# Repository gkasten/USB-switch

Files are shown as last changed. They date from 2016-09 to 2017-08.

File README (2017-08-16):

These scripts work with a USB switcher board to enable automated testing of an
Android device in host mode. They were written as part of Benjamin Fair's
(benjaminfair@) internship during summer 2016. For more information contact his
host Glenn Kasten (gkasten@).

In order to use the scripts in this directory, you must install some
dependencies. These dependencies vary based on which version of the board you
wish to use. See below for more information.

The scripts require a udev rules file to be installed which is included as
"49-ftdi.rules". Install it to "/etc/udev/rules.d/49-ftdi.rules" then run
"udevadm trigger" as root or reboot. The scripts can also be run as root instead
of installing the rules file.

The following kernel drivers/modules may interfere with access to the ftdi
chip on the board and so may have to be unloaded/blacklisted:
        ftdi_sio
        usbserial

usbswitch.py    Supports initial USB switch prototype with an Adafruit FT232H
                GPIO chip. Requires Adafruit_GPIO library from
                https://github.com/adafruit/Adafruit_Python_GPIO

usbswitch2.py   Supports new single-board switch (red PCB). Only requires
                libftdi1-dev which is in most distributions' repos. Could easily
                be ported to C and statically compiled to eliminate all
                dependencies.

adb.sh          Simple wrapper for adb that handles switching to debug mode and
                back to run mode after executing a command.

full.sh         Example script that shows how to use the switch to run tests
                using the WALT device and app in a fully automated way.

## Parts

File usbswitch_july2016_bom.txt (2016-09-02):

Partlist exported from /usr/local/google/home/benjaminfair/eagle/usbswitch2/usbswitch_july2016.sch at 8/1/16 6:14 PM

Part Value            Device           Package          Description                       MF MPN OC_FARNELL OC_NEWARK
C1   4.7uF            C-USC1210K       C1210K           CAPACITOR, American symbol                                   
C2   0.1uF            C-USC0805K       C0805K           CAPACITOR, American symbol                                   
C3   0.1uF            C-USC0805K       C0805K           CAPACITOR, American symbol                                   
C4   0.1uF            C-USC0805K       C0805K           CAPACITOR, American symbol                                   
C5   0.1uF            C-USC0805K       C0805K           CAPACITOR, American symbol                                   
IC1  MAX4906ELA       MAX4906ELA       UDFN10           High-/Full-Speed USB 2.0 Switches        unknown    unknown  
JP1  MOLEX-47346-0001 MOLEX-47346-0001 MOLEX-47364-0001 MICRO USB B, BOTTOM MOUNT                                    
JP2                   PN87520          PN87520          BERG USB connector                       unknown    unknown  
JP3  MOLEX-47346-0001 MOLEX-47346-0001 MOLEX-47364-0001 MICRO USB B, BOTTOM MOUNT                                    
JP4                   PINHD-1X5        1X05             PIN HEADER                                                   
Q1   FDN336P          PMOSSOT23        SOT-23           MOS FET                                  unknown    unknown  
Q2   FDN336P          PMOSSOT23        SOT-23           MOS FET                                  unknown    unknown  
Q3   FDN335N          NMOSSTO23        SOT-23           MOS FET                                                      
Q4   FDN335N          NMOSSTO23        SOT-23           MOS FET                                                      
R1   10K              R-US_R0805W      R0805W           RESISTOR, American symbol                                    
R2   10K              R-US_R0805W      R0805W           RESISTOR, American symbol                                    
R3   10K              R-US_R0805W      R0805W           RESISTOR, American symbol                                    
R4   10K              R-US_R0805W      R0805W           RESISTOR, American symbol                                    
R6   10K              R-US_R0805W      R0805W           RESISTOR, American symbol                                    
R7   10K              R-US_R0805W      R0805W           RESISTOR, American symbol                                    
R8   10K              R-US_R0805W      R0805W           RESISTOR, American symbol                                    
R_ID 124K             R-US_R0805W      R0805W           RESISTOR, American symbol                                    
U1   FT245RL          FT245RL          SSOP28DB         USB FIFO Controller

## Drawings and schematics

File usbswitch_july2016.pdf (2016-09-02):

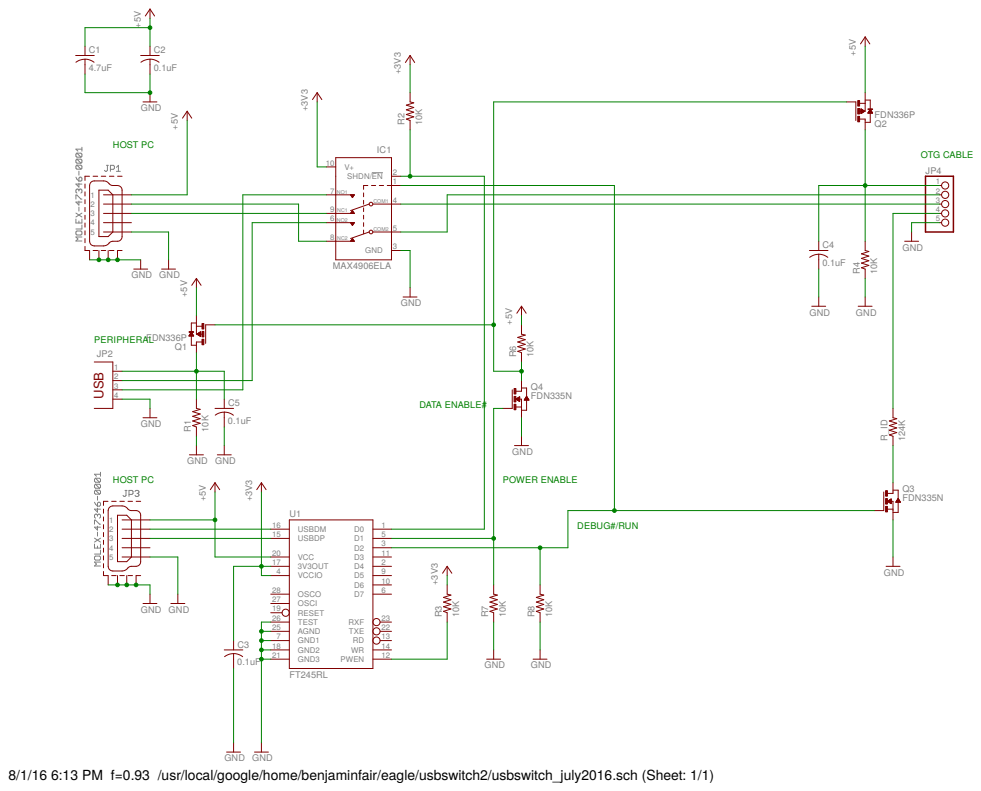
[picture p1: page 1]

4 | C5

8/1/16 6:13 PM f=0.93 /usr/local/google/home/benjaminfair/eagle/usbswitch2/usbswitch_july2016.sch (Sheet: 1/1)

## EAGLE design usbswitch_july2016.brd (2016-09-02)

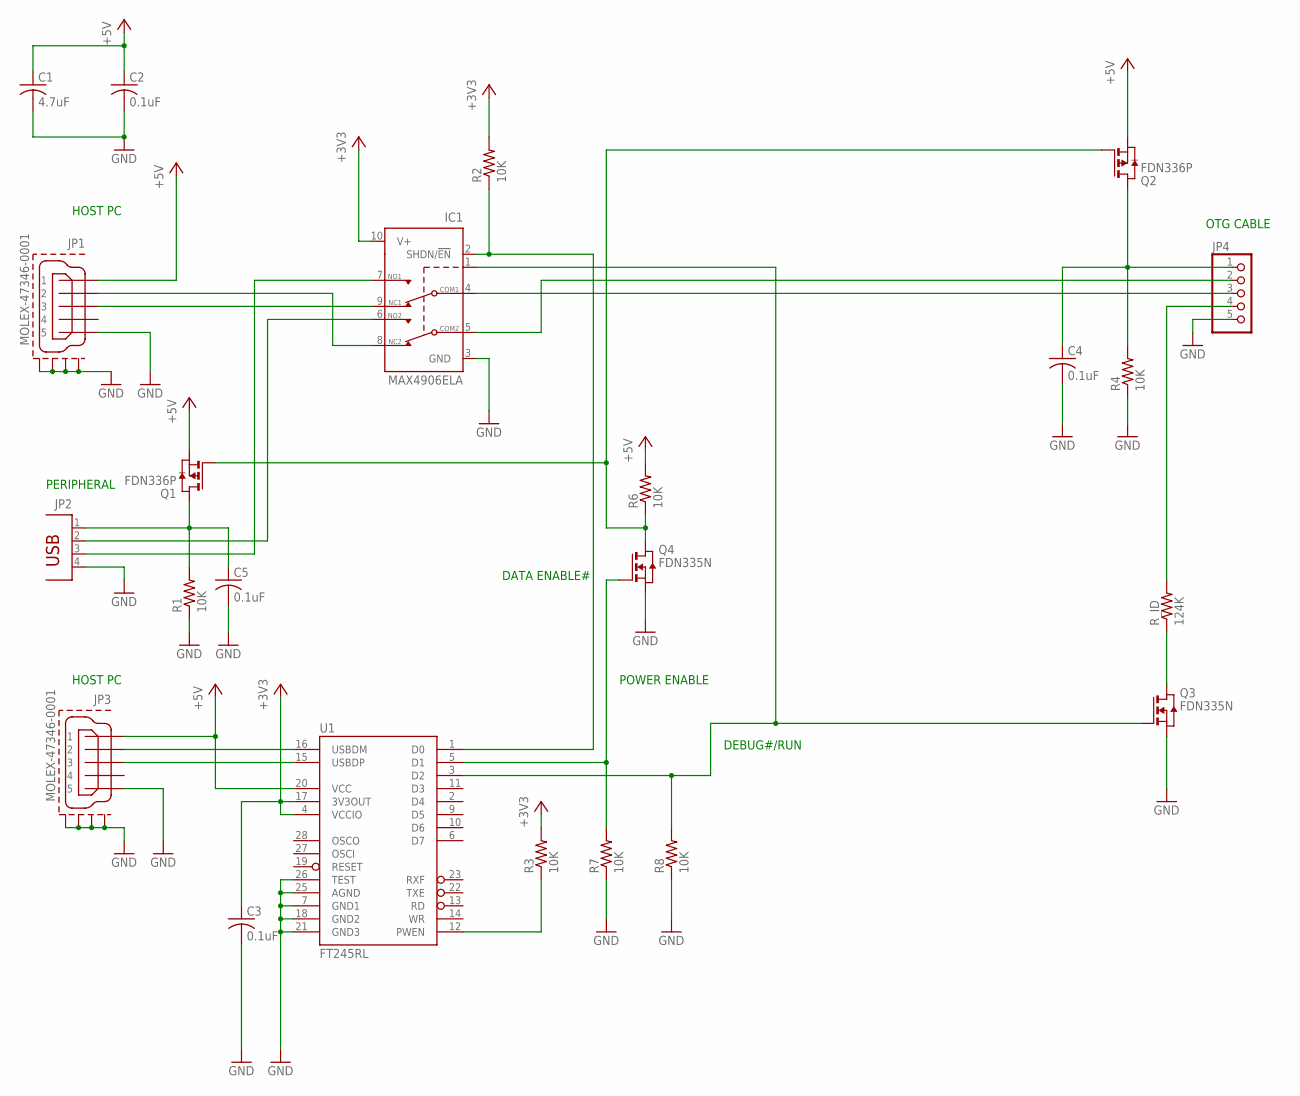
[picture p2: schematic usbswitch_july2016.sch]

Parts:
C1: 4.7uF; C1210K
C2, C3, C4, C5: 0.1uF; C0805K
IC1: MAX4906ELA; UDFN10
JP1, JP3: MOLEX-47346-0001; MOLEX-47364-0001
JP2: PN87520
JP4: PINHD-1X5; 1X05
Q1, Q2: FDN336P; SOT-23
Q3, Q4: FDN335N; SOT-23
R1, R2, R3, R4, R6, R7, R8: 10K; R0805W
R_ID: 124K; R0805W
U1: FT245RL; SSOP28DB

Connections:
+3V3: C3.1, IC1.10 (V+), R2.2, R3.2, U1.4 (VCCIO), U1.17 (3V3OUT)
+5V: C1.1, C2.1, JP1.1, JP3.1, Q1.2 (S), Q2.2 (S), R6.2, U1.20 (VCC)
GND: C1.2, C2.2, C3.2, C4.2, C5.2, IC1.3 (GND), JP1.5, JP1.GND1, JP1.GND2, JP1.GND3, JP1.GND4, JP2.4, JP3.5, JP3.GND1, JP3.GND2, JP3.GND3, JP3.GND4, JP4.5, Q3.2 (S), Q4.2 (S), R1.1, R4.1, R7.1, R8.1, U1.7 (GND1), U1.18 (GND2), U1.21 (GND3), U1.25 (AGND), U1.26 (TEST)
unnamed: IC1.4 (COM1), JP4.3
unnamed: IC1.2 (SHDN/!EN), R2.1, U1.1 (D0)
unnamed: C5.1, JP2.1, Q1.1 (D), R1.2
unnamed: C4.1, JP4.1, Q2.1 (D), R4.2
unnamed: IC1.9 (NC1), JP1.3
unnamed: IC1.8 (NC2), JP1.2
unnamed: Q3.1 (D), R_ID.1
unnamed: Q4.3 (G), R7.2, U1.5 (D1)
unnamed: IC1.6 (NO2), JP2.2
unnamed: IC1.7 (NO1), JP2.3
unnamed: JP3.2, U1.16 (USBDM)
unnamed: IC1.1 (IN), Q3.3 (G), R8.2, U1.3 (D2)
unnamed: Q1.3 (G), Q2.3 (G), Q4.1 (D), R6.1
unnamed: R3.1, U1.12 (PWEN)
unnamed: JP4.4, R_ID.2
unnamed: IC1.5 (COM2), JP4.2
unnamed: JP3.3, U1.15 (USBDP)

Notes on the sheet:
PERIPHERAL
OTG CABLE
HOST PC
DATA ENABLE#
DEBUG#/RUN
POWER ENABLE

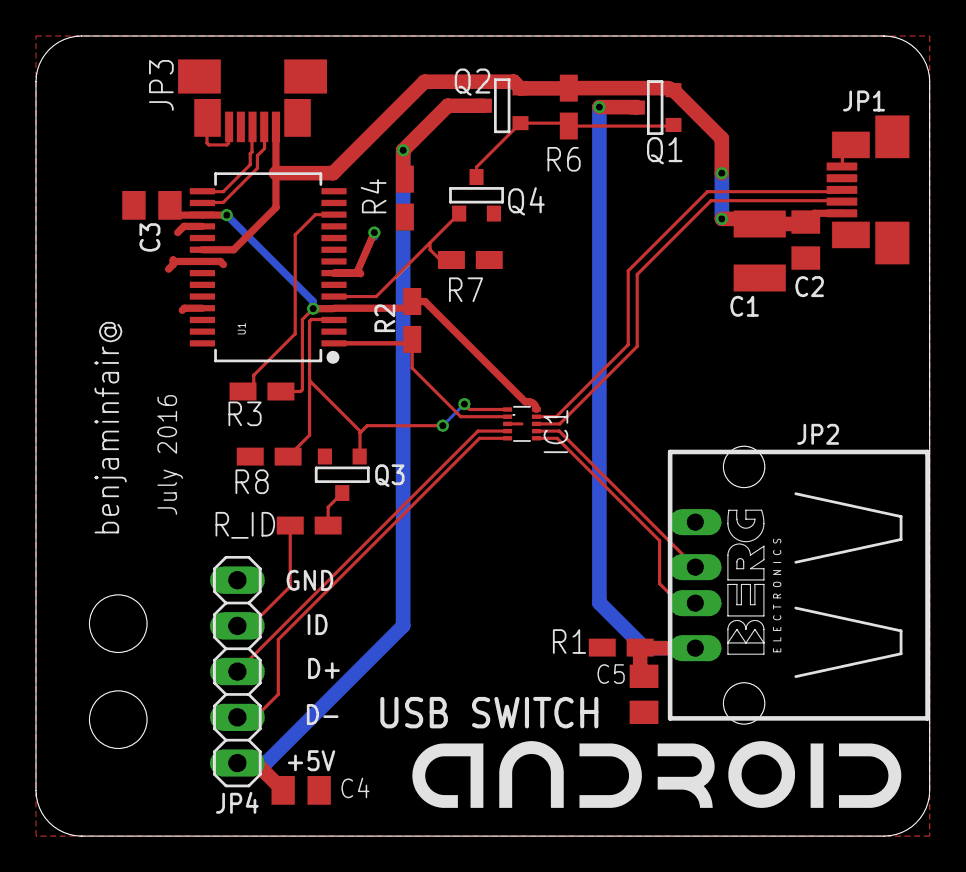
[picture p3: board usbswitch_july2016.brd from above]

Board: 2 copper layers, 49.6 x 44.5 mm, 24 parts (0 on the bottom side), 20 nets.

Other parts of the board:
U$1: ANDROID_MARK_25

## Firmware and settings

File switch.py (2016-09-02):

#!/usr/bin/python2.7

# Copyright (C) 2016 The Android Open Source Project
#
# Licensed under the Apache License, Version 2.0 (the "License");
# you may not use this file except in compliance with the License.
# You may obtain a copy of the License at
#
#      http://www.apache.org/licenses/LICENSE-2.0
#
# Unless required by applicable law or agreed to in writing, software
# distributed under the License is distributed on an "AS IS" BASIS,
# WITHOUT WARRANTIES OR CONDITIONS OF ANY KIND, either express or implied.
# See the License for the specific language governing permissions and
# limitations under the License.

import argparse

import time
import Adafruit_GPIO as GPIO
import Adafruit_GPIO.FT232H as FT232H

def switch(mode):
#  FT232H.use_FT232H()

  ft232h = FT232H.FT232H()

  ft232h.setup(8, GPIO.IN)
  ft232h.setup(9, GPIO.OUT)
  ft232h.output(9, GPIO.HIGH)
  ft232h.setup(10, GPIO.OUT)
  ft232h.output(10, GPIO.LOW)

  if mode == "toggle":
    do_toggle(ft232h)
  else:
    do_clear(ft232h)
    if mode == "run":
      do_toggle(ft232h)
    
def do_toggle(ft232h):
  ft232h.output(9, GPIO.LOW)
  time.sleep(0.1)
  ft232h.output(9, GPIO.HIGH)

def do_clear(ft232h):
  ft232h.output(10, GPIO.HIGH)
  time.sleep(0.1)
  ft232h.output(10, GPIO.LOW)

if __name__ == '__main__':
  parser = argparse.ArgumentParser(description="Control the USB switcher.")
  parser.add_argument("mode", choices=["toggle", "run", "debug"],
                      default="toggle", nargs='?',
                      help="what mode the USB switcher should be placed into")
  args = parser.parse_args()
  switch(args.mode)

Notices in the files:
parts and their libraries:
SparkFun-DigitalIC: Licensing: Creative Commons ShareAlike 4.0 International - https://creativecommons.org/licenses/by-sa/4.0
